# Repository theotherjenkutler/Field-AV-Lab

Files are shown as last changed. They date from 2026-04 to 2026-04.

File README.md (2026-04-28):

<h2>Field AV Lab</h2>



Field AV Lab is an electronics prototyping system geared towards circuit education and 
rapid prototyping for AV performance circuits. It has two 3.5mm IO, a dedicated headphone 
amplifier/audio output and VGA input/output for CHA/V style VGA video hacking. There are 
on board potentiometers, a light sensitive resistor and two LEDS for visualizing LFOs and 
general sanity checks. It is meant to pick up where the now discontinued Om Synth left off.

This design is a collaboration between Wavefield (wavefield.media) and Jen Kutler (jenkutler.com)
based on the Om Synth by Peter Edwards of Casper Electronics (casperelectronics.com) combined with
the CHA/V by Jonas Bers (jonasbers.com) PCB Artwork by Paloma Kop (palomakop.tv).

Instructional videos for the Om Synth and 'recipes' translate to this board e.g.
<br>https://www.youtube.com/watch?v=FaoJaLmZaL4
<br>https://www.youtube.com/watch?v=t7JYOIYqMEY
<br>https://www.youtube.com/watch?v=ECSYLTB_sbw

It also offers a lower cost point of entry than the LABOR but can be used practically in the
same way for instructional videos like these:
<br>https://www.youtube.com/watch?v=Xbl1xwFR3eg

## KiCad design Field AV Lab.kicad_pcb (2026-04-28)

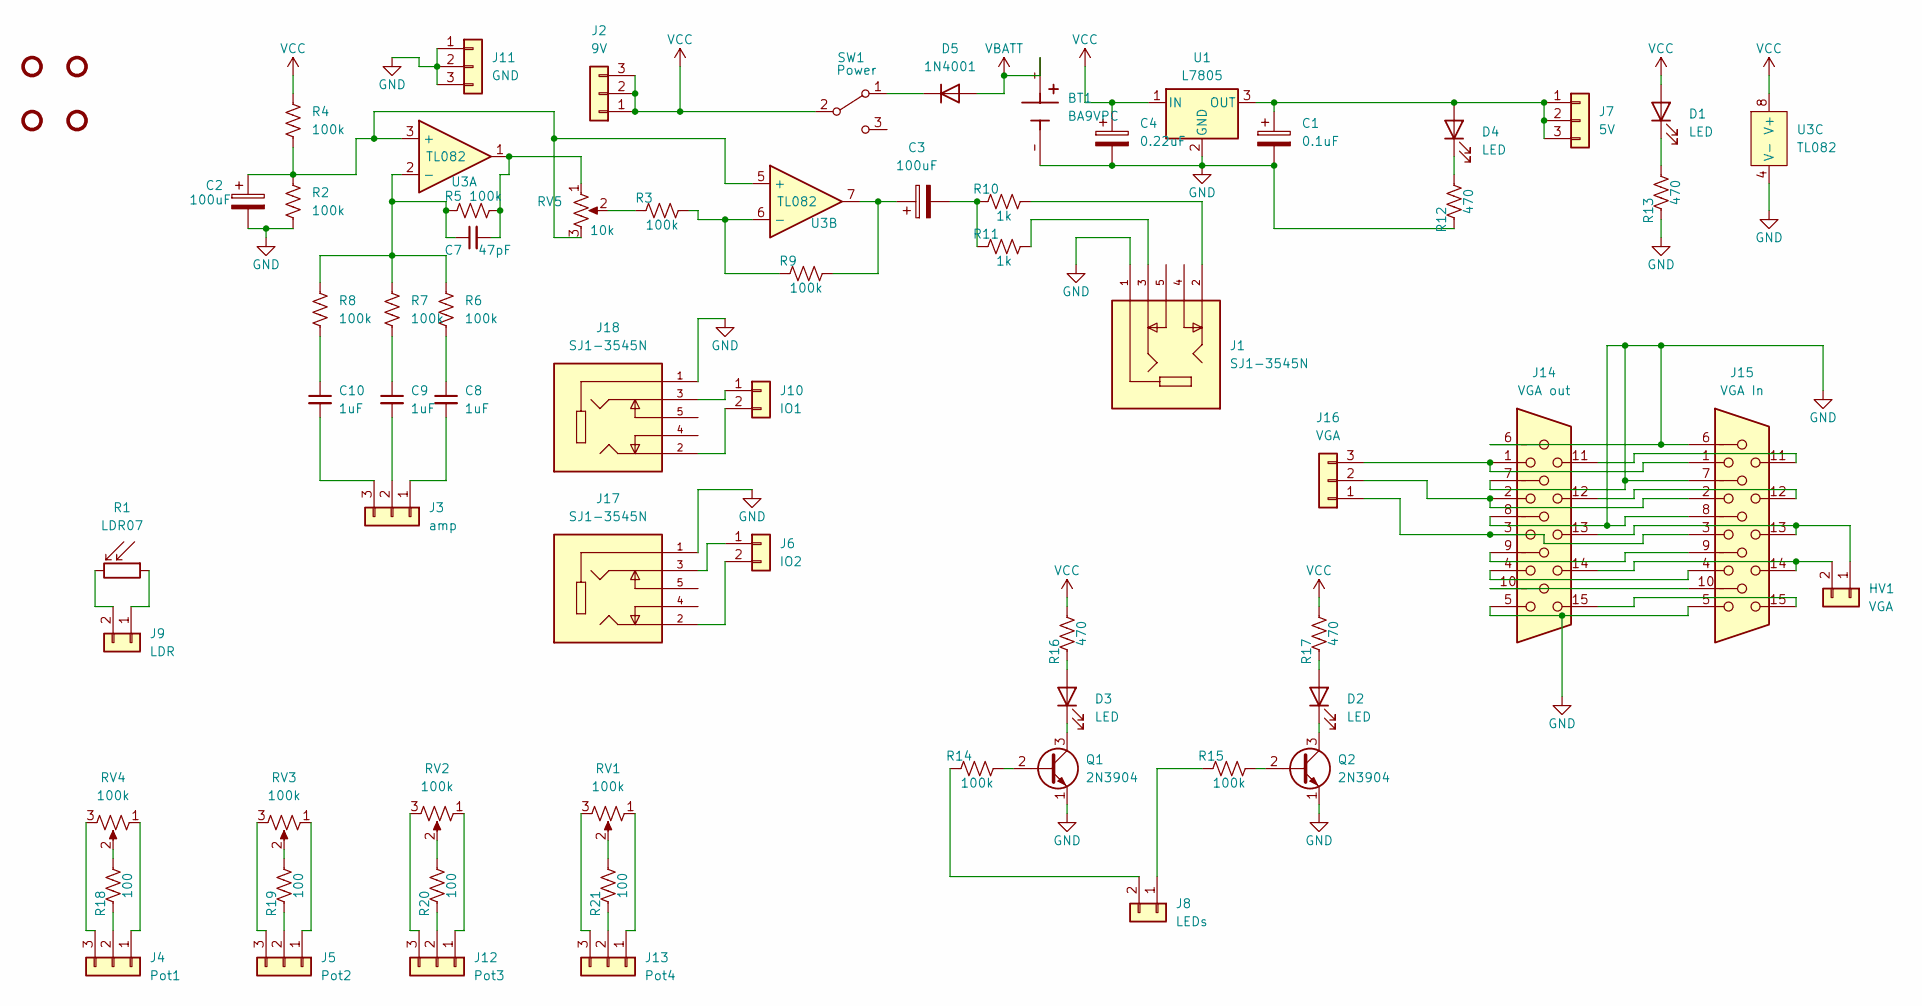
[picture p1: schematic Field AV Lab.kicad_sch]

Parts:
BT1: BA9VPC; BAT_BA9VPC; PARTREV E
C1: 0.1uF; CP_Radial_D5.0mm_P2.50mm
C2, C3: 100uF; CP_Radial_D5.0mm_P2.50mm
C4: 0.22uF; CP_Radial_D5.0mm_P2.50mm
C7: 47pF; C_Disc_D5.0mm_W2.5mm_P2.50mm
C8, C9, C10: 1uF; C_Disc_D5.0mm_W2.5mm_P2.50mm
D1, D2, D3, D4: LED; LED_D3.0mm
D5: 1N4001; D_DO-41_SOD81_P10.16mm_Horizontal
HV1: VGA; PinHeader_1x02_P2.54mm_Vertical; Part Number 1-0201FBV0T
J1, J17, J18: SJ1-3545N; CUI_SJ1-3545N; PARTREV 1.03
J2: 9V; PinHeader_1x03_P2.54mm_Vertical; Part Number 1-0301FBV0T
J3: amp; PinHeader_1x03_P2.54mm_Vertical; Part Number 1-0301FBV0T
J4: Pot1; PinHeader_1x03_P2.54mm_Vertical; Part Number 1-0301FBV0T
J5: Pot2; PinHeader_1x03_P2.54mm_Vertical; Part Number 1-0301FBV0T
J6: IO2; PinHeader_1x02_P2.54mm_Vertical; Part Number 1-0201FBV0T
J7: 5V; PinHeader_1x03_P2.54mm_Vertical; Part Number 1-0301FBV0T
J8: LEDs; PinHeader_1x02_P2.54mm_Vertical; Part Number 1-0201FBV0T
J9: LDR; PinHeader_1x02_P2.54mm_Vertical; Part Number 1-0201FBV0T
J10: IO1; PinHeader_1x02_P2.54mm_Vertical; Part Number 1-0201FBV0T
J11: GND; PinHeader_1x03_P2.54mm_Vertical; Part Number 1-0301FBV0T
J12: Pot3; PinHeader_1x03_P2.54mm_Vertical; Part Number 1-0301FBV0T
J13: Pot4; PinHeader_1x03_P2.54mm_Vertical; Part Number 1-0301FBV0T
J14: VGA out; DSUB-15_Socket_Vertical_P2.77x2.84mm
J15: VGA In; DSUB-15_Socket_Vertical_P2.77x2.84mm
J16: VGA; PinHeader_1x03_P2.54mm_Vertical; Part Number 1-0301FBV0T
Q1, Q2: 2N3904; TO-92_Inline
R1: LDR07; R_LDR_5.1x4.3mm_P3.4mm_Vertical
R2, R3, R4, R5, R6, R7, R8, R9, R14, R15: 100k; R_Axial_DIN0204_L3.6mm_D1.6mm_P5.08mm_Horizontal
R10, R11: 1k; R_Axial_DIN0204_L3.6mm_D1.6mm_P5.08mm_Horizontal
R12, R13, R16, R17: 470; R_Axial_DIN0204_L3.6mm_D1.6mm_P5.08mm_Horizontal
R18, R19, R20, R21: 100; R_Axial_DIN0204_L3.6mm_D1.6mm_P5.08mm_Horizontal
RV1, RV2, RV3, RV4: 100k; Potentiometer_TT_P0915N
RV5: 10k; Potentiometer_TT_P0915N
ST1, ST2, ST3, ST4: Standoff
SW1: Power; Slide_SPDT_PTH_11.6x4.0mm
U1: L7805; TO-220-3
U3: TL082; DIP-8_W7.62mm; Part Number TL082CPT; JLCPCB ID C2652280

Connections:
GND: BT1.-, C1.2, C2.2, C4.2, J1.1, J11.1, J11.2, J11.3, J14.5, J14.6, J14.7, J14.8, J15.5, J15.6, J15.7, J15.8, J17.1, J18.1, Q1.1 (E), Q2.1 (E), R2.2, R12.1, R13.1, U1.2 (GND), U3.4 (V-)
unnamed: C3.1, R9.2, U3.7
unnamed: C3.2, R10.1, R11.1
unnamed: C7.2, R5.1, RV5.1, U3.1
unnamed: C8.1, R6.2
unnamed: C9.1, R7.2
unnamed: C10.1, R8.2
unnamed: D1.1 (K), R13.2
unnamed: D2.2 (A), R17.1
unnamed: D2.1 (K), Q2.3 (C)
unnamed: D3.2 (A), R16.1
unnamed: D3.1 (K), Q1.3 (C)
unnamed: C1.1, D4.2 (A), J7.1, J7.2, J7.3, U1.3 (OUT)
unnamed: D4.1 (K), R12.2
unnamed: D5.1 (K), SW1.1 (A)
unnamed 15: HV1.1, J14.13, J15.13; also elsewhere on the board
unnamed 16: HV1.2, J14.14, J15.14; also elsewhere on the board
unnamed: J1.2, R10.2
unnamed: J1.3, R11.2
unnamed: C8.2, J3.1
unnamed: C9.2, J3.2
unnamed: C10.2, J3.3
unnamed: J4.1, RV4.1
unnamed: J4.2, R18.1
unnamed: J4.3, RV4.3
unnamed: J5.1, RV3.1
unnamed: J5.2, R19.1
unnamed: J5.3, RV3.3
unnamed: J6.1, J17.3
unnamed: J6.2, J17.2
unnamed: J8.1, R15.1
unnamed: J8.2, R14.1
unnamed: J9.1, R1.1
unnamed: J9.2, R1.2
unnamed: J10.1, J18.3
unnamed: J10.2, J18.2
unnamed: J12.1, RV2.1
unnamed: J12.2, R20.1
unnamed: J12.3, RV2.3
unnamed: J13.1, RV1.1
unnamed: J13.2, R21.1
unnamed: J13.3, RV1.3
unnamed: J14.4, J15.4
unnamed: J14.9, J15.9
unnamed: J14.10, J15.10
unnamed: J14.11, J15.11
unnamed: J14.12, J15.12
unnamed: J14.15, J15.15
unnamed 48: J14.3, J15.3, J16.1; also elsewhere on the board
unnamed 49: J14.2, J15.2, J16.2; also elsewhere on the board
unnamed 50: J14.1, J15.1, J16.3; also elsewhere on the board
unnamed: Q1.2 (B), R14.2
unnamed: Q2.2 (B), R15.2
unnamed: R3.1, RV5.2
unnamed: R18.2, RV4.2
unnamed: R19.2, RV3.2
unnamed: R20.2, RV2.2
unnamed: R21.2, RV1.2
unnamed: C2.1, R2.1, R4.2, RV5.3, U3.3 (+), U3.5 (+)
unnamed: C7.1, R5.2, R6.1, R7.1, R8.1, U3.2 (-)
unnamed: R3.2, R9.1, U3.6 (-)
VBATT: BT1.+, D5.2 (A)
VCC: C4.1, D1.2 (A), J2.1, J2.2, J2.3, R4.1, R16.2, R17.2, SW1.2 (B), U1.1 (IN), U3.8 (V+)

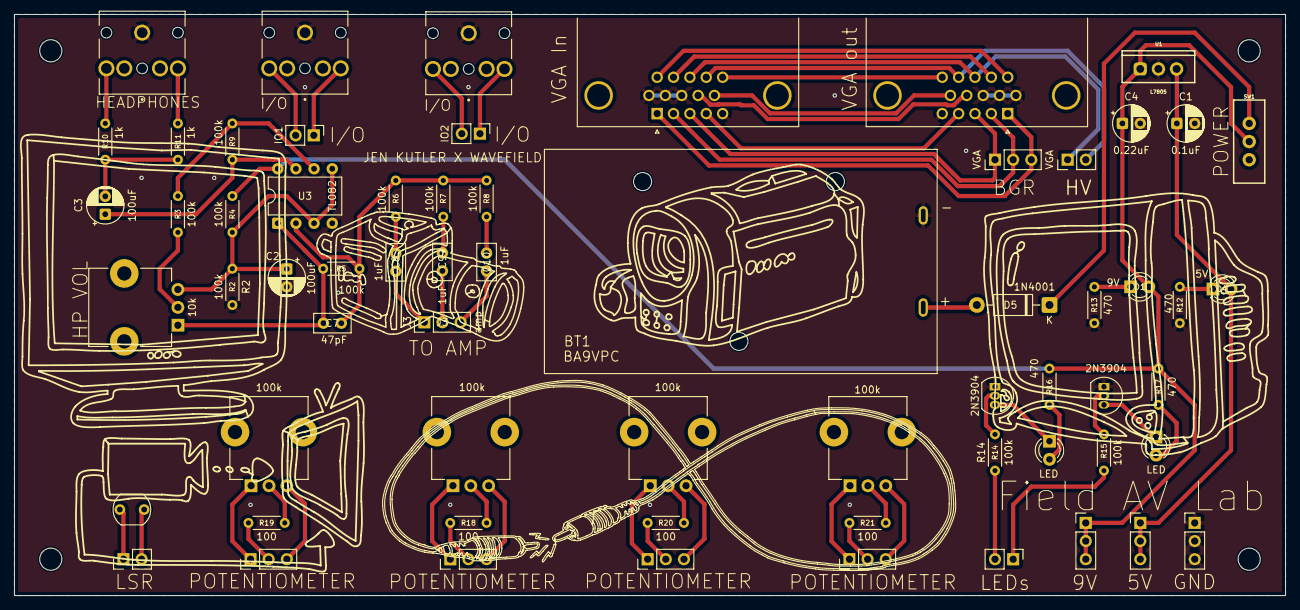
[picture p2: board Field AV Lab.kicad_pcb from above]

Board: 2 copper layers, 177.8 x 81.3 mm, 68 parts (0 on the bottom side), 63 nets.

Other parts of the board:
HV: VGA; PinHeader_1x02_P2.54mm_Vertical
RGB: VGA; PinHeader_1x03_P2.54mm_Vertical

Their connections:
unnamed 15: HV.1; also elsewhere on the board
unnamed 16: HV.2; also elsewhere on the board
unnamed 48: RGB.1; also elsewhere on the board
unnamed 49: RGB.2; also elsewhere on the board
unnamed 50: RGB.3; also elsewhere on the board
